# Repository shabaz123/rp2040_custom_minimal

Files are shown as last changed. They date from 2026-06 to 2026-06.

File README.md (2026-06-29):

# RP2040 Minimal Project for KiCad

This repository contains a modified version of the Raspberry Pi RP2040 Minimal design.

The modified version is more suited to recent KiCad versions (for instance KiCad 10), and it improves things slightly if the board is to be produced, for fewer 0402 parts rotating/sliding/tombstoning issues.

## Schematic

The schematic includes the RP2040 microcontroller along with supporting circuitry. The USB connector is USB-C, unlike the original Micro USB. 

**NOTE**: The GPIO connectors from the original schematic have been removed, so that the schematic is ready for custom additions.

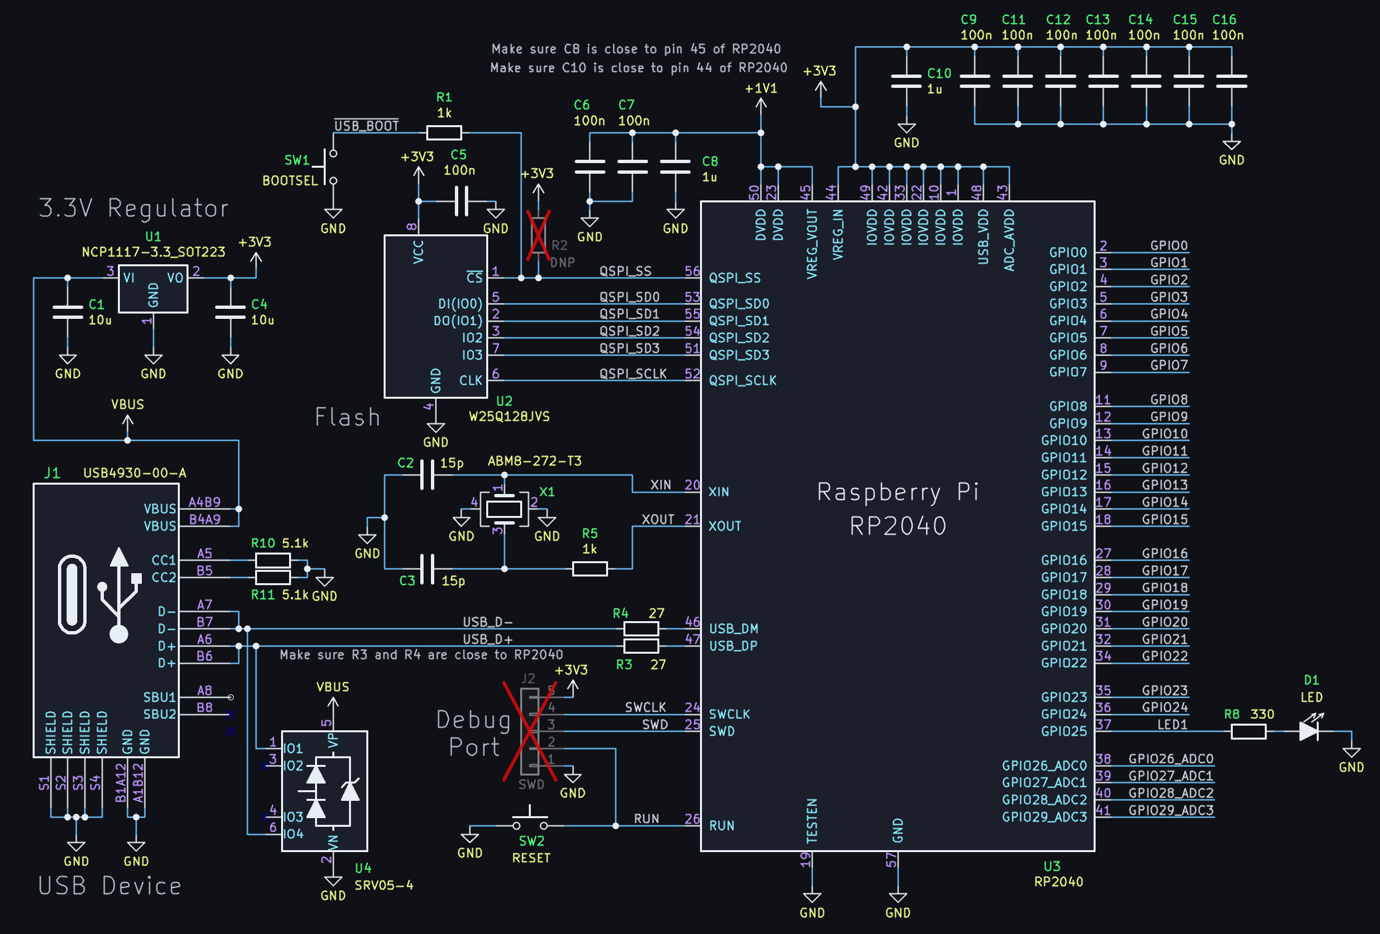
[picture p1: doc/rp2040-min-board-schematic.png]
Schematic


## PCB Layout

The image here shows the top side copper. The bottom side is nearly all ground plane, apart from a few traces that carry 1.1V core power, and one at the USB-C connector end to allow cables to be inserted in any orientation.

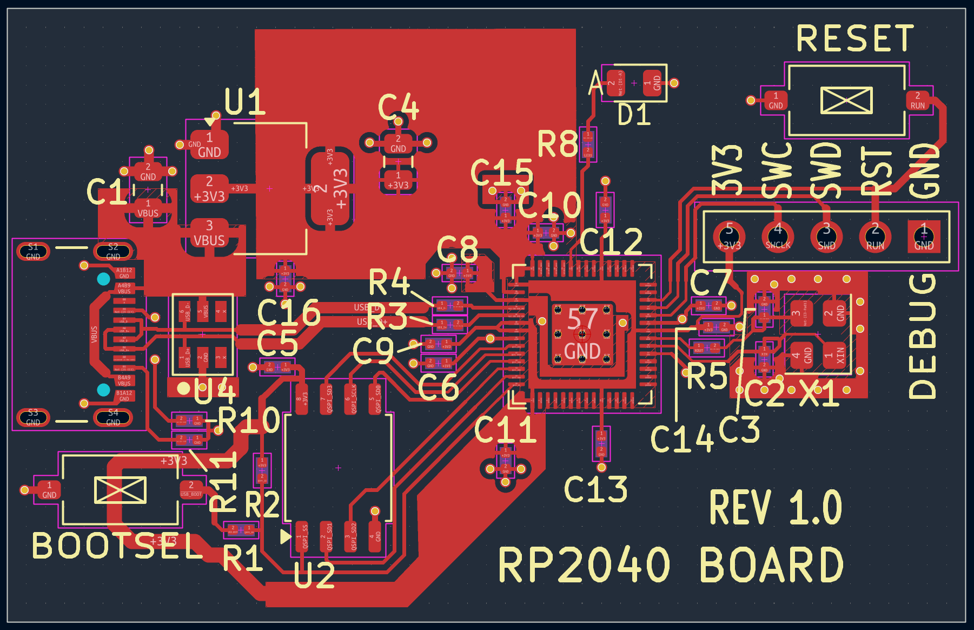
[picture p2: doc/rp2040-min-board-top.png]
PCB Layout


## 3D Render

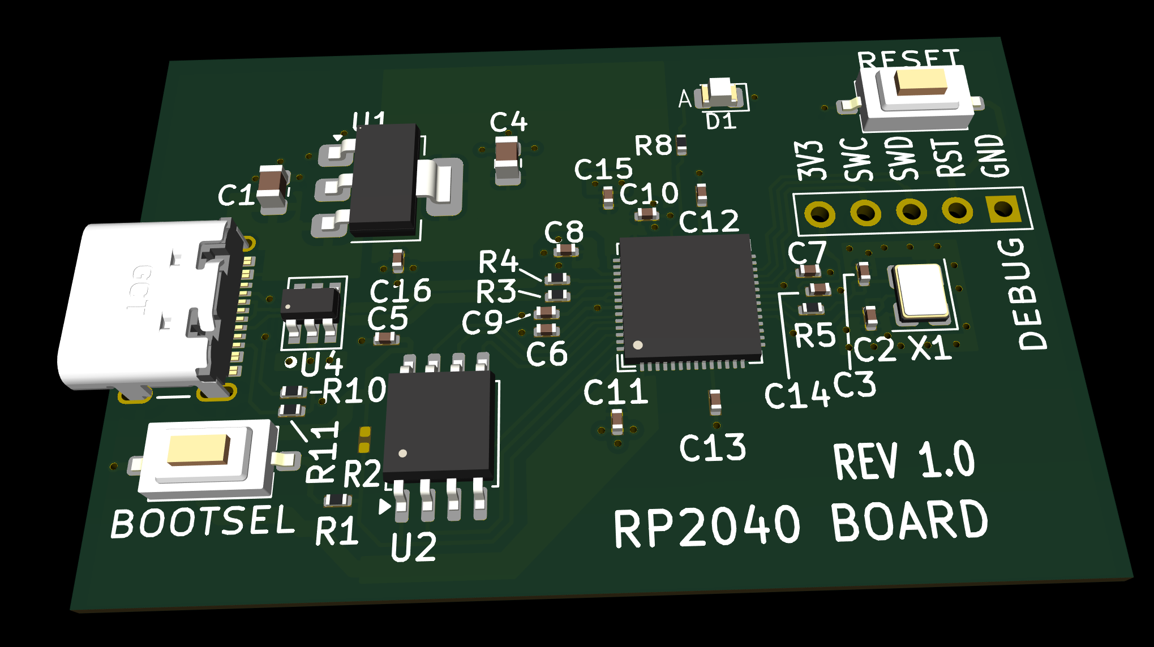
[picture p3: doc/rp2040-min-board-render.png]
3D Render


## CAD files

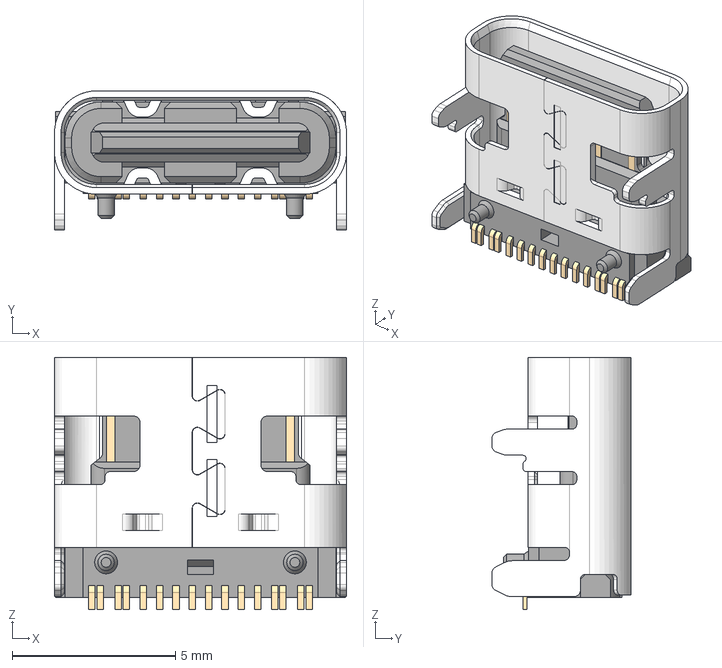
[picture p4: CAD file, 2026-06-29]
custom_minimal_kicad/3D/USB4930-00-A.stp
8.94 x 4.26 x 7.73 mm
USB4930-00-A_PART1
USB4930-00-A_PART2

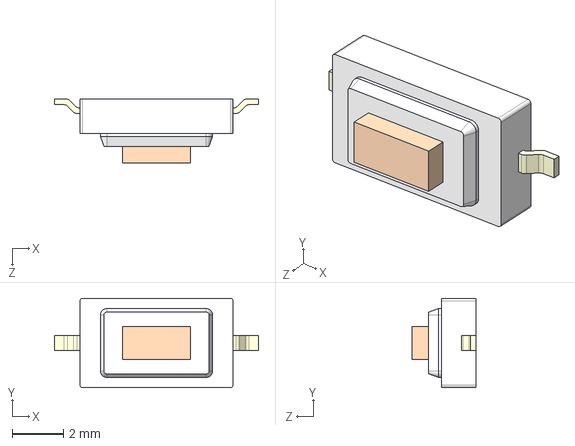
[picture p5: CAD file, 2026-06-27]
custom_minimal_kicad/3D/G73 button.STEP
8.00 x 3.50 x 2.50 mm

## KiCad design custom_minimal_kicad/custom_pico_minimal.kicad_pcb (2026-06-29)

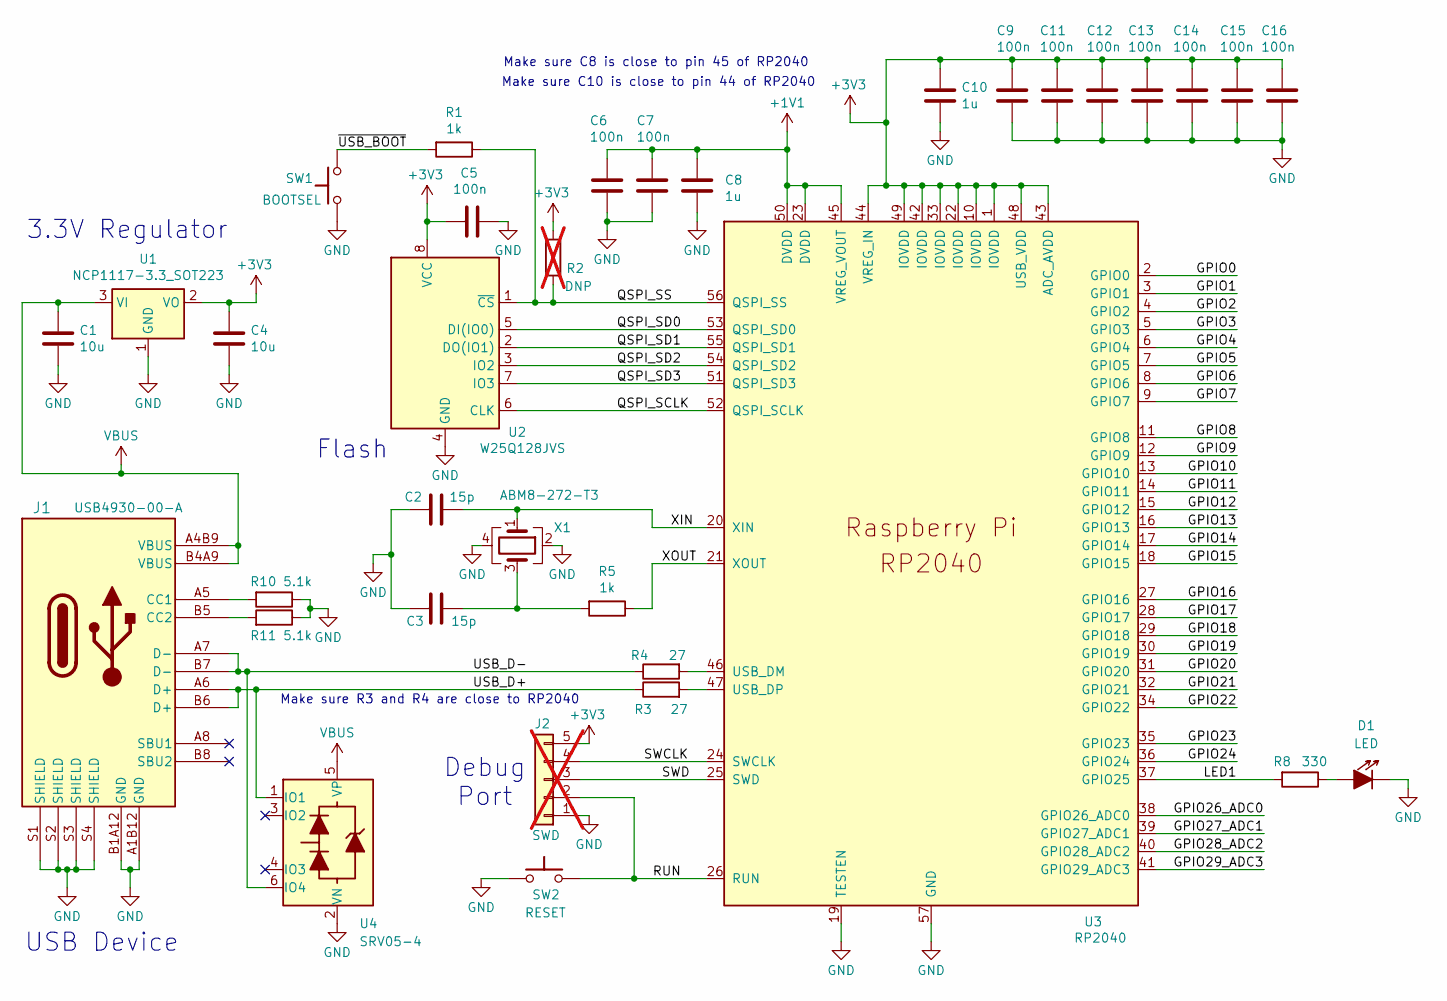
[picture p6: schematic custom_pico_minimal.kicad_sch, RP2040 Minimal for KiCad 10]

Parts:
C1, C4: 10u; C_0805_2012Metric; LCSC Part # C126586
C2, C3: 15p; 0402-footprint-improved-Cap3D; LCSC Part # C76950
C5, C6, C7, C9, C11, C12, C13, C14, C15, C16: 100n; 0402-footprint-improved-Cap3D; LCSC Part # C152814
C8, C10: 1u; 0402-footprint-improved-Cap3D; LCSC Part # C88945
D1: LED; LED_0805_2012Metric; LCSC Part # C2297
J1: USB4930-00-A; CONN_USB4930-00-A_GCT; LCSC Part # C2988369
J2: SWD; PinHeader_1x05_P2.54mm_Vertical; not fitted
R1, R5: 1k; 0402-footprint-improved-Res3D; LCSC Part # C852624
R2: DNP; 0402-footprint-improved-Res3D; not fitted
R3, R4: 27; 0402-footprint-improved-Res3D; LCSC Part # C384351
R8: 330; 0402-footprint-improved-Res3D; LCSC Part # C71626
R10, R11: 5.1k; 0402-footprint-improved-Res3D; LCSC Part # C723526
SW1: BOOTSEL; Tact-SW-TS-1101-6mm-3.6mm; LCSC Part # C500065
SW2: RESET; Tact-SW-TS-1101-6mm-3.6mm; LCSC Part # C500065
U1: NCP1117-3.3_SOT223; SOT-223-3_TabPin2; LCSC Part # C26537
U2: W25Q128JVS; SOIC-8_5.3x5.3mm_P1.27mm; LCSC Part # C97521
U3: RP2040; RP2040-QFN-56; LCSC Part # C2040
U4: SRV05-4; SOT23-6-SRV05-04; LCSC Part # C2836319
X1: ABM8-272-T3; Crystal_SMD_3225-4Pin_3.2x2.5mm; LCSC Part # C20625731

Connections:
+1V1: C6.1, C7.1, C8.1, U3.23 (DVDD), U3.45 (VREG_VOUT), U3.50 (DVDD)
+3V3: C4.1, C5.1, C9.1, C10.1, C11.1, C12.1, C13.1, C14.1, C15.1, C16.1, J2.5, R2.1, U1.2 (VO), U2.8 (VCC), U3.1 (IOVDD), U3.10 (IOVDD), U3.22 (IOVDD), U3.33 (IOVDD), U3.42 (IOVDD), U3.43 (ADC_AVDD), U3.44 (VREG_IN), U3.48 (USB_VDD), U3.49 (IOVDD)
/GPIO0: U3.2 (GPIO0)
/GPIO1: U3.3 (GPIO1)
/GPIO2: U3.4 (GPIO2)
/GPIO3: U3.5 (GPIO3)
/GPIO4: U3.6 (GPIO4)
/GPIO5: U3.7 (GPIO5)
/GPIO6: U3.8 (GPIO6)
/GPIO7: U3.9 (GPIO7)
/GPIO8: U3.11 (GPIO8)
/GPIO9: U3.12 (GPIO9)
/GPIO10: U3.13 (GPIO10)
/GPIO11: U3.14 (GPIO11)
/GPIO12: U3.15 (GPIO12)
/GPIO13: U3.16 (GPIO13)
/GPIO14: U3.17 (GPIO14)
/GPIO15: U3.18 (GPIO15)
/GPIO16: U3.27 (GPIO16)
/GPIO17: U3.28 (GPIO17)
/GPIO18: U3.29 (GPIO18)
/GPIO19: U3.30 (GPIO19)
/GPIO20: U3.31 (GPIO20)
/GPIO21: U3.32 (GPIO21)
/GPIO22: U3.34 (GPIO22)
/GPIO23: U3.35 (GPIO23)
/GPIO24: U3.36 (GPIO24)
/GPIO26_ADC0: U3.38 (GPIO26_ADC0)
/GPIO27_ADC1: U3.39 (GPIO27_ADC1)
/GPIO28_ADC2: U3.40 (GPIO28_ADC2)
/GPIO29_ADC3: U3.41 (GPIO29_ADC3)
/LED1: R8.2, U3.37 (GPIO25)
/QSPI_SCLK: U2.6 (CLK), U3.52 (QSPI_SCLK)
/QSPI_SD0: U2.5 (DI(IO0)), U3.53 (QSPI_SD0)
/QSPI_SD1: U2.2 (DO(IO1)), U3.55 (QSPI_SD1)
/QSPI_SD2: U2.3 (IO2), U3.54 (QSPI_SD2)
/QSPI_SD3: U2.7 (IO3), U3.51 (QSPI_SD3)
/QSPI_SS: R1.1, R2.2, U2.1 (~CS), U3.56 (QSPI_SS)
/RUN: J2.2, SW2.2, U3.26 (RUN)
/SWCLK: J2.4, U3.24 (SWCLK)
/SWD: J2.3, U3.25 (SWD)
/USB_D+: J1.A6 (D+), J1.B6 (D+), R3.1, U4.1 (IO1)
/USB_D-: J1.A7 (D-), J1.B7 (D-), R4.1, U4.6 (IO4)
/XIN: C2.1, U3.20 (XIN), X1.1
/XOUT: R5.1, U3.21 (XOUT)
/~USB_BOOT: R1.2, SW1.2
GND: C1.2, C2.2, C3.2, C4.2, C5.2, C6.2, C7.2, C8.2, C9.2, C10.2, C11.2, C12.2, C13.2, C14.2, C15.2, C16.2, D1.1 (K), J1.A1B12 (GND), J1.B1A12 (GND), J1.S1 (SHIELD), J1.S2 (SHIELD), J1.S3 (SHIELD), J1.S4 (SHIELD), J2.1, R10.1, R11.1, SW1.1, SW2.1, U1.1 (GND), U2.4 (GND), U3.19 (TESTEN), U3.57 (GND), U4.2 (VN), X1.2, X1.4
unnamed: C3.1, R5.2, X1.3
unnamed: D1.2 (A), R8.1
unnamed: J1.A5 (CC1), R10.2
unnamed: J1.B5 (CC2), R11.2
unnamed: R4.2, U3.46 (USB_DM)
unnamed: R3.2, U3.47 (USB_DP)
VBUS: C1.1, J1.A4B9 (VBUS), J1.B4A9 (VBUS), U1.3 (VI), U4.5 (VP)

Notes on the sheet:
3.3V Regulator
Make sure C8 is close to pin 45 of RP2040
USB Device
Make sure C10 is close to pin 44 of RP2040
Make sure R3 and R4 are close to RP2040
Debug Port
Flash

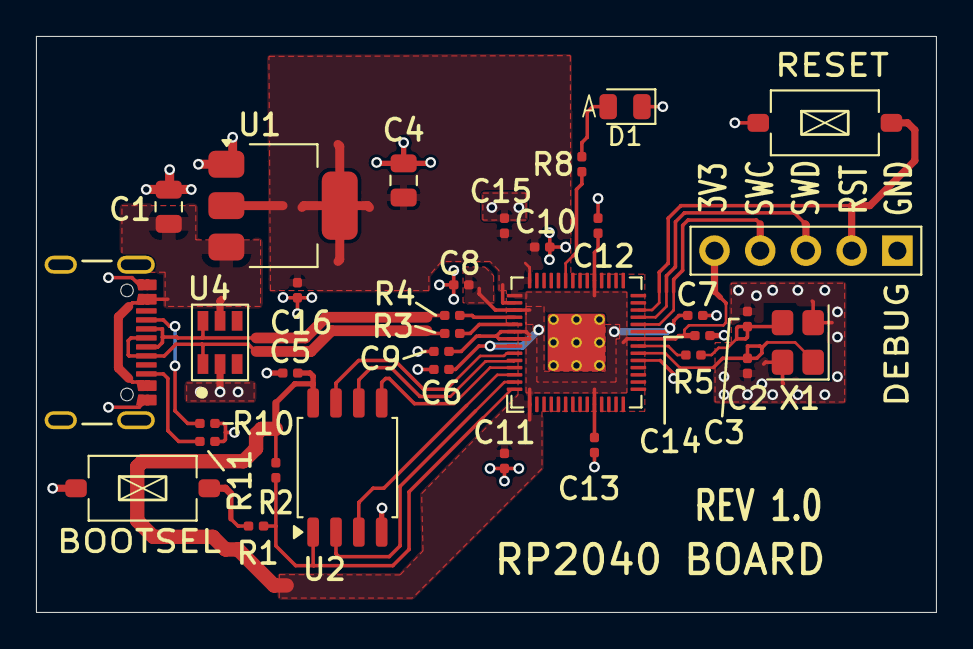
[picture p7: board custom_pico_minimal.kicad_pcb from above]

Board: 2 copper layers, 50.0 x 32.0 mm, 34 parts (0 on the bottom side), 25 nets.

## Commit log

2026-06-27 Revise README for schematic and PCB layout details
    Updated schematic and PCB layout descriptions for clarity and accuracy.
2026-06-29 Fix description of PCB layout traces
    Corrected 'a few traces' to 'one trace' for accuracy.

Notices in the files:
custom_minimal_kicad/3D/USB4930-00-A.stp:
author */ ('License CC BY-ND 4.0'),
